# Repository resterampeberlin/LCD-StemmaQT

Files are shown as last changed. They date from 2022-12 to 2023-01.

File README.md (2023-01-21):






              
# Purpose

# Credits

This open source code project is has been proudfully produced in Berlin (and other places around the globe) by

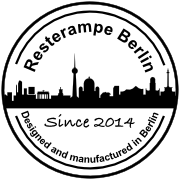
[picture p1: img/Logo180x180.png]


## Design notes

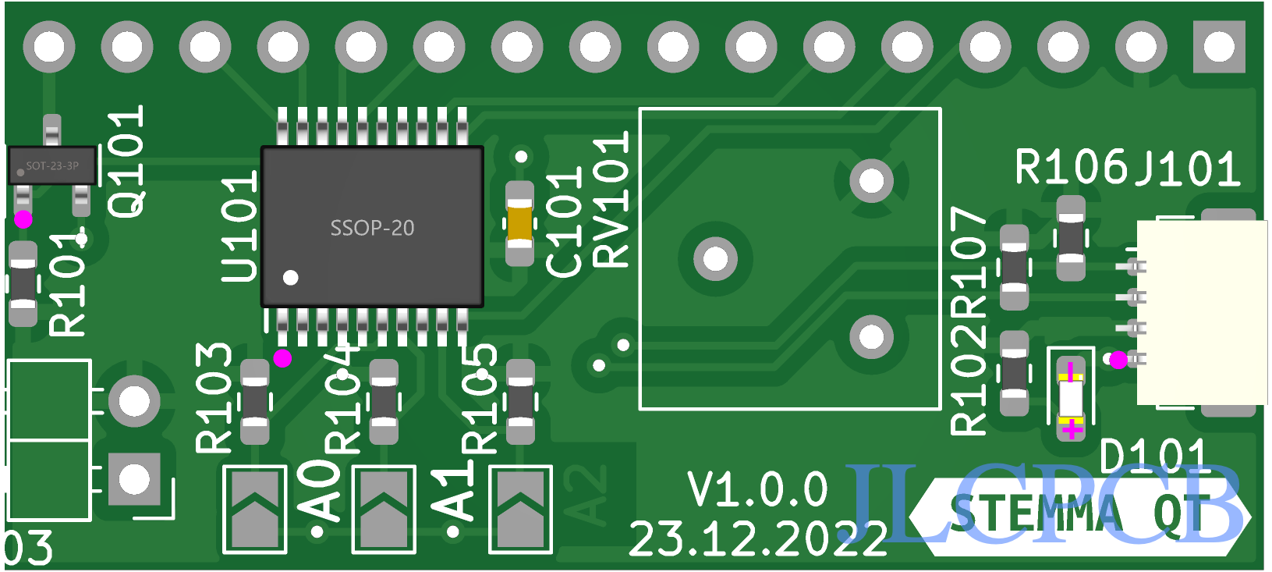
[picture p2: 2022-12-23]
jlcpcb/capture-2022-12-23T21_58_43.198Z.png

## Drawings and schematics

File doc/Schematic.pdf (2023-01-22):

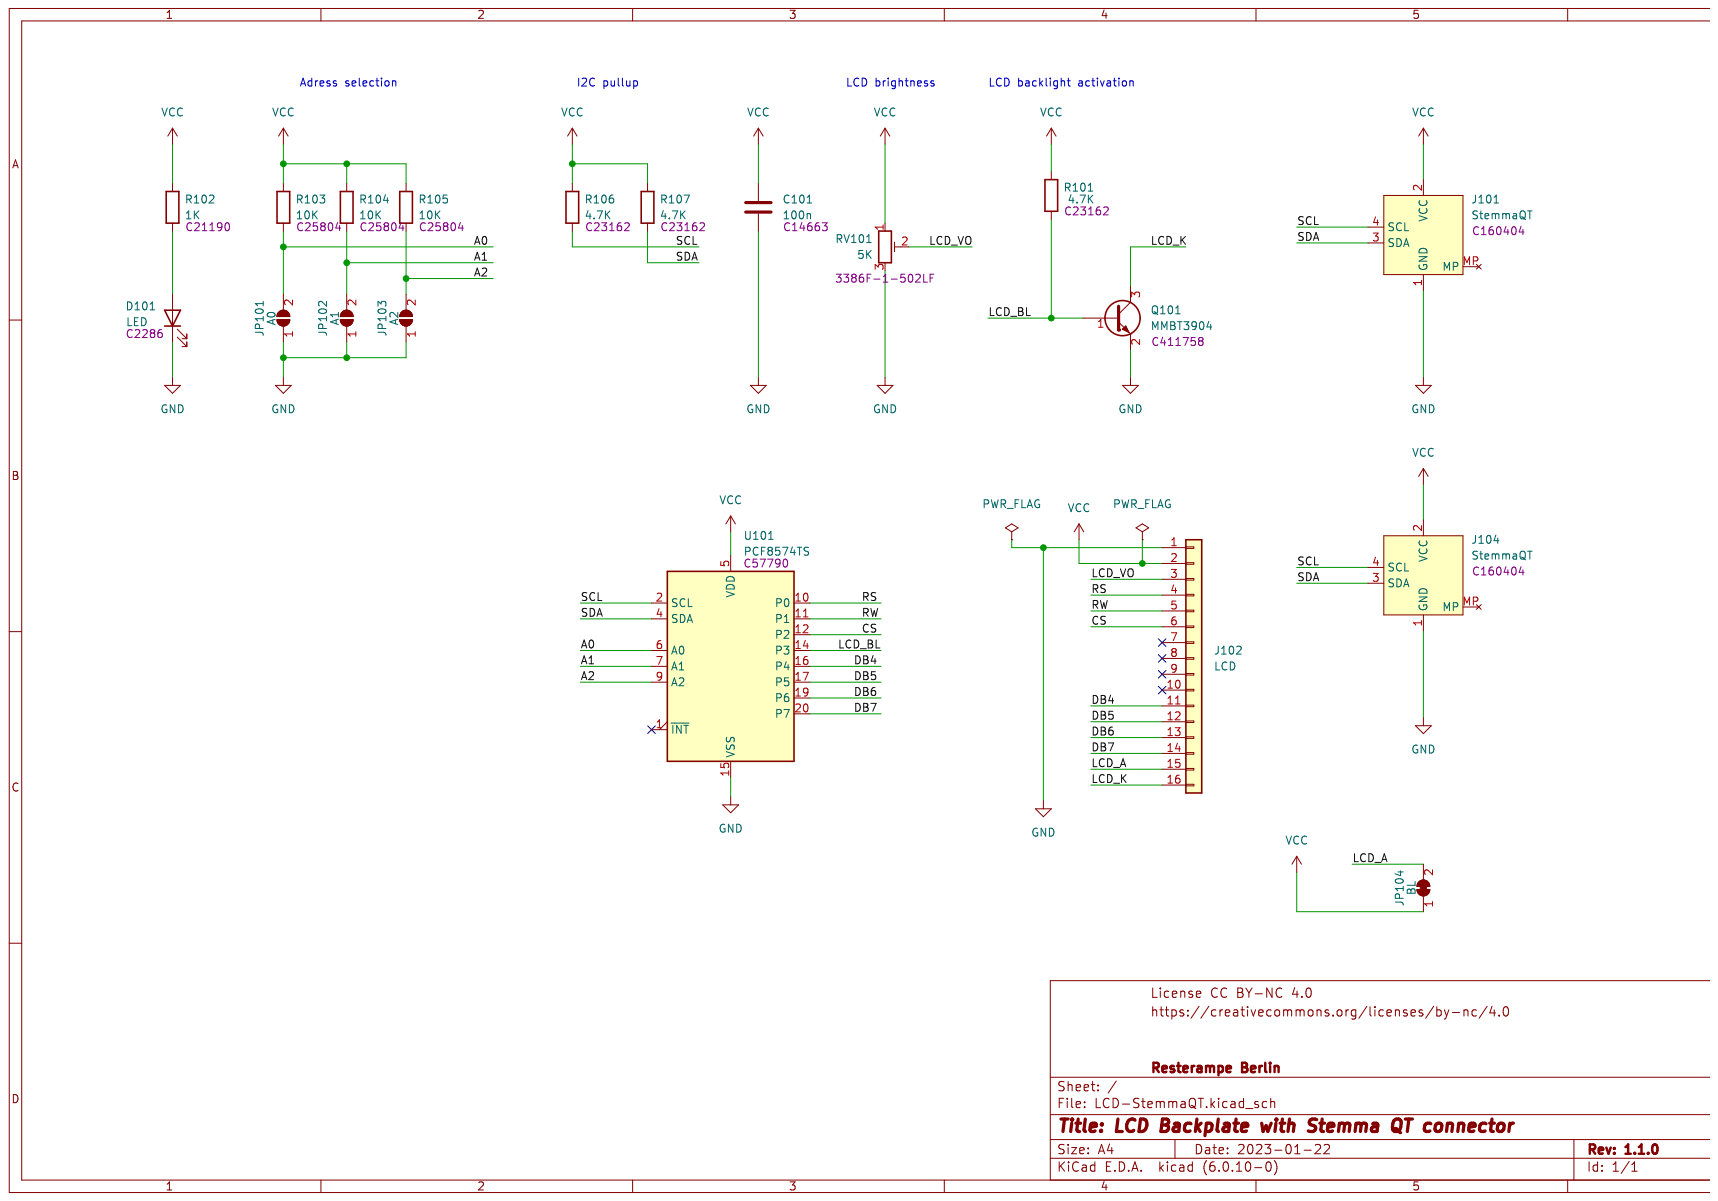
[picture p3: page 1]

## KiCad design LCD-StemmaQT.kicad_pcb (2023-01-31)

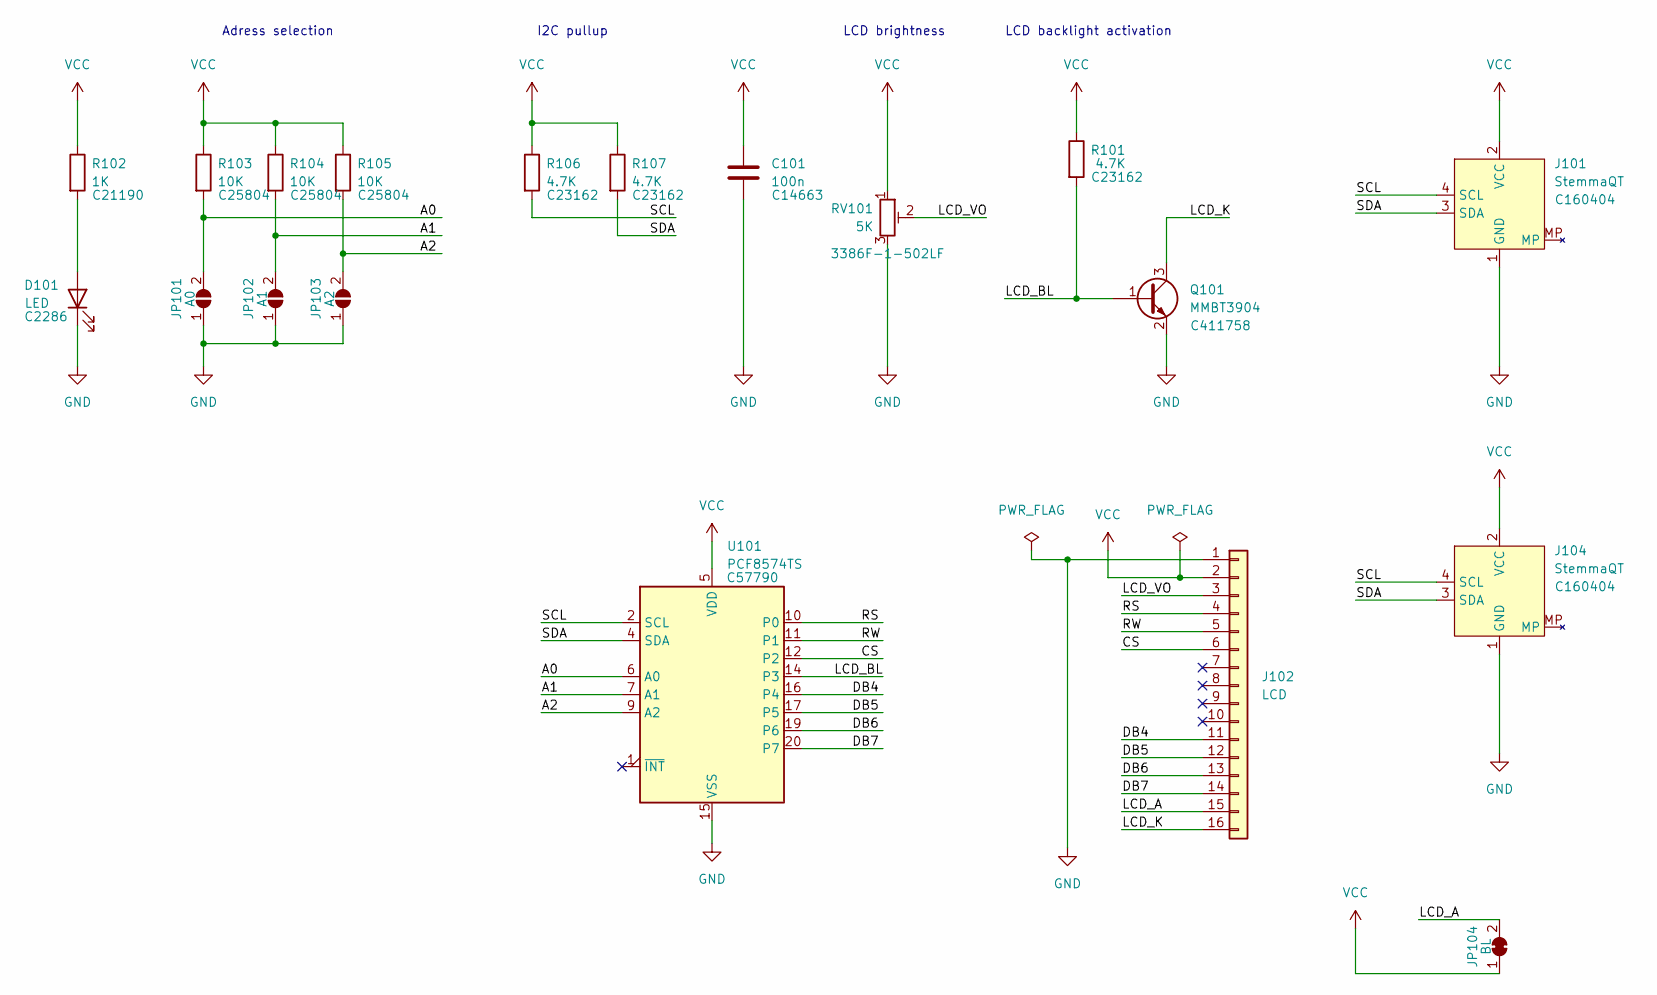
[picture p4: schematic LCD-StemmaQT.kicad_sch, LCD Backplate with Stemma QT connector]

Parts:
C101: 100n; C_0603_1608Metric_Pad1.08x0.95mm_HandSolder; LCSC C14663
D101: LED; LED_0603_1608Metric_Pad1.05x0.95mm_HandSolder; LCSC C2286
J101, J104: StemmaQT; JST_SH_SM04B-SRSS-TB_1x04-1MP_P1.00mm_Horizontal; LCSC C160404
J102: LCD; PinHeader_1x16_P2.54mm_Vertical
JP101: A0; SolderJumper-2_P1.3mm_Open_TrianglePad1.0x1.5mm
JP102: A1; SolderJumper-2_P1.3mm_Open_TrianglePad1.0x1.5mm
JP103: A2; SolderJumper-2_P1.3mm_Open_TrianglePad1.0x1.5mm
JP104: BL; SolderJumper-2_P1.3mm_Bridged_Pad1.0x1.5mm
Q101: MMBT3904; SOT-23; LCSC C411758
R101, R106, R107: 4.7K; R_0603_1608Metric_Pad0.98x0.95mm_HandSolder; LCSC C23162
R102: 1K; R_0603_1608Metric_Pad0.98x0.95mm_HandSolder; LCSC C21190
R103, R104, R105: 10K; R_0603_1608Metric_Pad0.98x0.95mm_HandSolder; LCSC C25804
RV101: 5K; Potentiometer_Bourns_3386F_Vertical; DigiKey 3386F-1-502LF
U101: PCF8574TS; SSOP-20_4.4x6.5mm_P0.65mm; LCSC C57790

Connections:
/A0: JP101.2 (B), R103.2, U101.6 (A0)
/A1: JP102.2 (B), R104.2, U101.7 (A1)
/A2: JP103.2 (B), R105.2, U101.9 (A2)
/CS: J102.6, U101.12 (P2)
/DB4: J102.11, U101.16 (P4)
/DB5: J102.12, U101.17 (P5)
/DB6: J102.13, U101.19 (P6)
/DB7: J102.14, U101.20 (P7)
/LCD_A: J102.15, JP104.2 (B)
/LCD_BL: Q101.1 (B), R101.2, U101.14 (P3)
/LCD_K: J102.16, Q101.3 (C)
/LCD_VO: J102.3, RV101.2
/RS: J102.4, U101.10 (P0)
/RW: J102.5, U101.11 (P1)
/SCL: J101.4 (SCL), J104.4 (SCL), R106.2, U101.2 (SCL)
/SDA: J101.3 (SDA), J104.3 (SDA), R107.2, U101.4 (SDA)
GND: C101.2, D101.1 (K), J101.1 (GND), J102.1, J104.1 (GND), JP101.1 (A), JP102.1 (A), JP103.1 (A), Q101.2 (E), RV101.3, U101.15 (VSS)
unnamed: D101.2 (A), R102.2
VCC: C101.1, J101.2 (VCC), J102.2, J104.2 (VCC), JP104.1 (A), R101.1, R102.1, R103.1, R104.1, R105.1, R106.1, R107.1, RV101.1, U101.5 (VDD)

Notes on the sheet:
Adress selection
LCD brightness
LCD backlight activation
I2C pullup

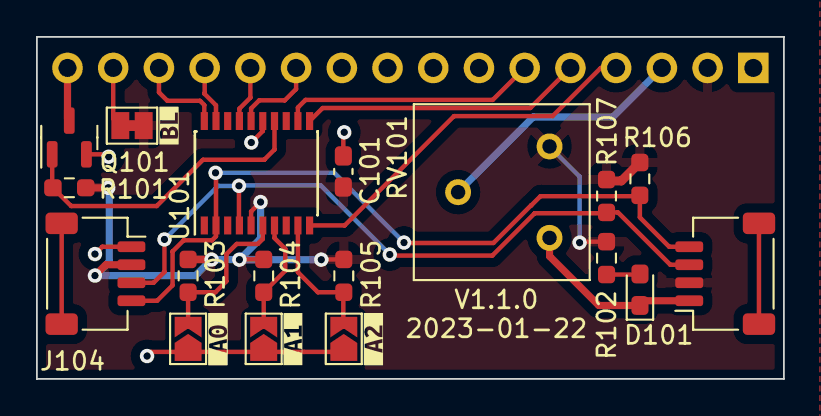
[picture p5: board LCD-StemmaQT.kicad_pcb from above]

Board: 2 copper layers, 41.5 x 19.0 mm, 23 parts (1 on the bottom side), 19 nets.

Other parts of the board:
kibuzzard-63CD50DB: G***; kibuzzard-63CD50DB
kibuzzard-63CD512B: G***; kibuzzard-63CD512B
kibuzzard-63CD5133: G***; kibuzzard-63CD5133
kibuzzard-63CD5139: G***; kibuzzard-63CD5139

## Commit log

2022-12-23 Non functional corrections on PCB
    [LCD-StemmaQT.kicad_pcb, LCD-StemmaQT.kicad_sch]
2023-01-05 added StemmaQT logo on PCB
    [LCD-StemmaQT.kicad_pcb, LCD-StemmaQT.kicad_sch]
2023-01-09 Stemma QT footprint corrected
    [LCD-StemmaQT.kicad_pcb, LCD-StemmaQT.kicad_sch]
2023-01-21 Documentation updated
    [LCD-StemmaQT.kicad_sch]
2023-01-22 Added second StemmaQT port
    [LCD-StemmaQT.kicad_pcb, LCD-StemmaQT.kicad_sch]

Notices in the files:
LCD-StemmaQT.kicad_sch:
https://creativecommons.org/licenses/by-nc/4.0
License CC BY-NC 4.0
